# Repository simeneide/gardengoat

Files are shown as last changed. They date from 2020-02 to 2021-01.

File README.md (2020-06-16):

# gardengoat

## Installation of raspberry pi

### Install os + wifi
1. Download full raspberian at  https://www.raspberrypi.org/downloads/raspbian/
2. Flash sd card
3. Create file "ssh" in boot directory
4. Connect pi to network
5. Set configs in `sudo raspi-config`
    a. Set wifi ssid+pwd
    b. Set host name to gardengoat
6. Clone this repository: `git clone https://github.com/simeneide/gardengoat.git`
	
### Install gps module
1. Set the following in raspi-config:https://learn.adafruit.com/adafruit-ultimate-gps-hat-for-raspberry-pi/pi-setup

### Installing motor driver
Following [this](https://learn.adafruit.com/adafruit-dc-and-stepper-motor-hat-for-raspberry-pi/installing-software) instructions to install driver to motor:
1. Enable I2C: https://learn.adafruit.com/adafruits-raspberry-pi-lesson-4-gpio-setup/configuring-i2c
2. Install library: `sudo pip3 install adafruit-circuitpython-motorkit`

### Other packages
- apriltags (https://pypi.org/project/apriltags/) (need `apt-get update && apt-get install cmake`)
- Installed by building here: `https://github.com/AprilRobotics/apriltag`

pip3 install jupyterlab
apt-get install emacs

### TORCH and TORCHVISION
Installed from wheel on these:
https://github.com/nmilosev/pytorch-arm-builds

But for rpi4 there was some errors, so I installed a wheel after reading this comment:
https://github.com/nmilosev/pytorch-arm-builds/issues/4#issuecomment-527433112

Install from his wheel a bit longer down the thread, and rename those _C.**.so and _d.**.so files to _C.so and _d.so.

Torchvision works, but Pillow 7.0.0 was too new, so downgraded to 6.1 after some random comments I found.

Step-by-step:
- `sudo pip3 install torch-1.1.0-cp37-cp37m-linux_armv7l.whl`

Then if you try to run `sudo python3 -c "import torch"` you get:

```
Traceback (most recent call last):
  File "<string>", line 1, in <module>
  File "/usr/local/lib/python3.7/dist-packages/torch/__init__.py", line 79, in <module>
    from torch._C import *
ModuleNotFoundError: No module named 'torch._C'
```
Can be fixed by the following:
```
cd /usr/local/lib/python3.7/dist-packages/torch
sudo mv _C.cpython-37m-arm-linux-gnueabi.so _C.so
sudo mv _dl.cpython-37m-arm-linux-gnueabi.so _dl.so
```

### Local Bluetooth keyboard
Using the python keyboard package and requires root to run.
Advantage: You can drive the car locally without need for stable wifi.

Need to be connected and paired to the keyboard:
Sometimes needs to be repaired:
```
bluetoothctl
remove 2C:33:61:E0:77:84
pair 2C:33:61:E0:77:84
connect 2C:33:61:E0:77:84
```
### ps4 controller
Doesnt work yet..

`sudo pip install pyPS4Controller`

sudo pip3 install ds4drv

sudo wget https://raw.githubusercontent.com/chrippa/ds4drv/master/udev/50-ds4drv.rules -O /etc/udev/rules.d/50-ds4drv.rules
sudo udevadm control --reload-rules
sudo udevadm trigger

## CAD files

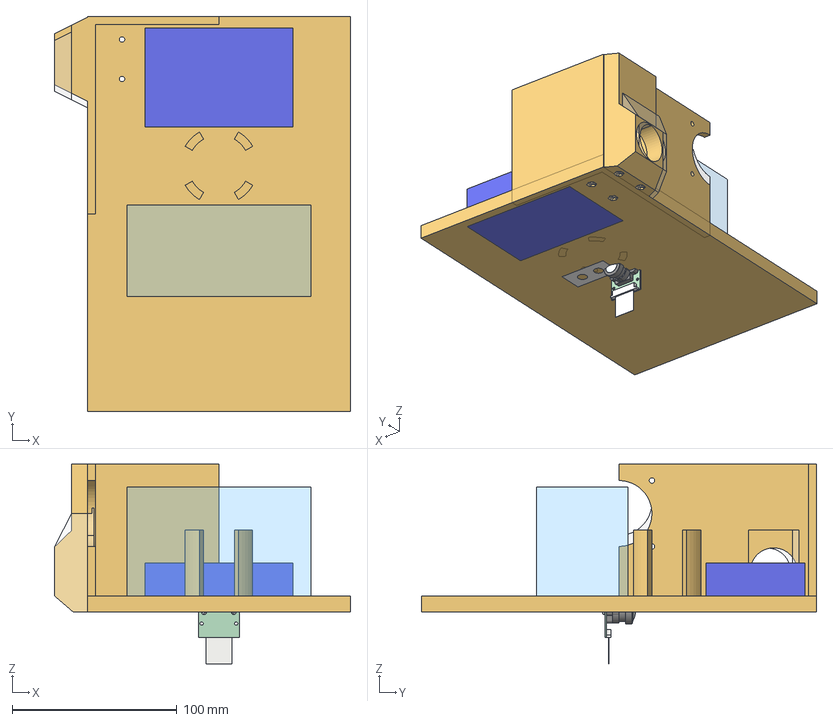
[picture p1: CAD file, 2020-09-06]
CAD/goat-ver3.FCStd
180.0 x 240.0 x 121.4 mm
Body-q11-lower
body-battery
body-full
body-rpi
Body-knife-blade
Raspberry Pi Camera (G) 160\X\B0
Raspberry Pi Camera (G) 160\X\B001
Raspberry Pi Camera (G) 160\X\B002
Raspberry Pi Camera (G) 160\X\B003
Raspberry Pi Camera (G) 160\X\B004
Raspberry Pi Camera (G) 160\X\B005
Raspberry Pi Camera (G) 160\X\B006
Raspberry Pi Camera (G) 160\X\B007

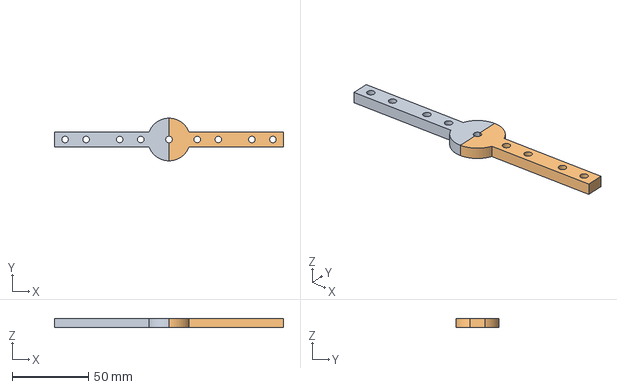
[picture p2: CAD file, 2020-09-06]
CAD/knifeblade.FCStd
150.0 x 28.0 x 6.00 mm
Body (Mirror #1)

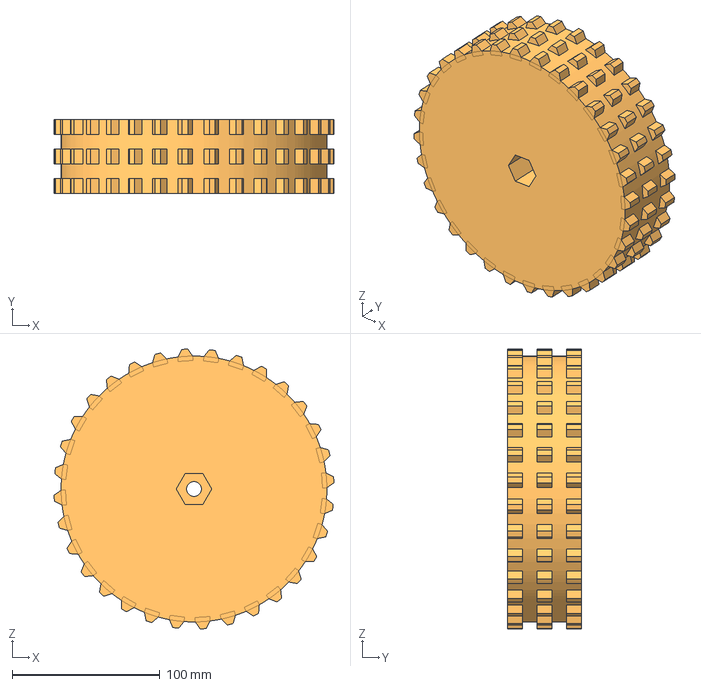
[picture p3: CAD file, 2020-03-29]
CAD/wheel-knast.FCStd
189.6 x 50.0 x 189.6 mm

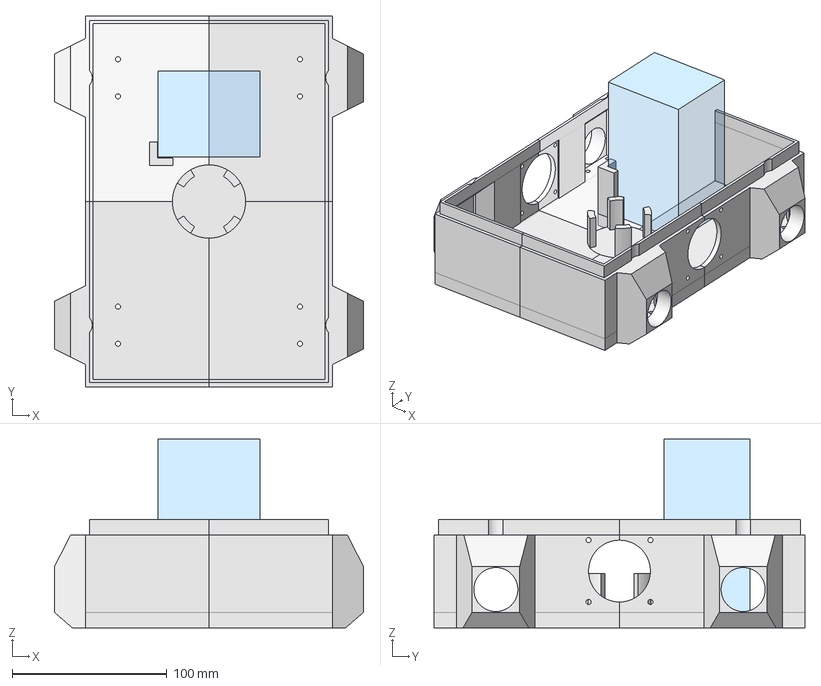
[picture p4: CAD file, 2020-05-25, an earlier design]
CAD/goat-ver2.FCStd
200.0 x 240.0 x 122.0 mm
Body-grasscutter
Body-q11-lower
Body-q11-lower (Mirror #1)
Body-q11-lower (Mirror #2)
Body-q11-lower (Mirror #3)
body-battery

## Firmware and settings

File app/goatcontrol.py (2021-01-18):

################
#### MOTOR ####
import cv2, queue, threading, time
import time
import numpy as np
import logging
import pyrealsense2 as rs
import sys
import time
import RPi.GPIO as GPIO
#import picamera
#import apriltag
# from gps3.agps3threaded import AGPS3mechanism
        
def output_list(pins, value):
    for pin in pins:
        GPIO.output(pin, value)

class Car:
    def __init__(self):
        self.gpio_map = {
            'left' : {
                'forward' : [6,26],
                'backward' : [13,20]
            },
            'right' : {
                'forward' : [5,19],
                'backward' : [12,16]
            }
        }
        GPIO.cleanup()
        GPIO.setmode(GPIO.BCM)
        for side, motors in self.gpio_map.items():
            for key, val in motors.items():
                print(f"{side}-{key}-{val}")
                GPIO.setup(val, GPIO.OUT)
        logging.info(f"driving controls initialized.")
        
    def drive(self, left=0, right=0, cut=False , *args, **kwargs):
        if left>=0:
            output_list(self.gpio_map['left']['forward'], left)
            output_list(self.gpio_map['left']['backward'], 0)
        if left<=0:
            output_list(self.gpio_map['left']['backward'], -left)
            output_list(self.gpio_map['left']['forward'], 0)
        if right>=0:
            output_list(self.gpio_map['right']['forward'], right)
            output_list(self.gpio_map['right']['backward'], 0)
        if right<=0:
            output_list(self.gpio_map['right']['backward'], -right)
            output_list(self.gpio_map['right']['forward'], 0)
            
    def close(self):
        GPIO.cleanup()
        
        
################
#### SENSORS ####
import asyncio
def rgb2gray(rgb):
    return np.dot(rgb[...,:3], [0.2989, 0.5870, 0.1140])

# GET GPS SIGNAL
class GPSTracker:
    def __init__(self):
        self.agps_thread = AGPS3mechanism()  # Instantiate AGPS3 Mechanisms
        self.agps_thread.stream_data()  # From localhost (), or other hosts, by example, (host='gps.ddns.net')
        self.agps_thread.run_thread()  # Throttle time to sleep after an empty lookup, default '()' 0.2 two tenths of a second

    def __call__(self):
        return {
            
            'lat' : self.agps_thread.data_stream.lat,
            'lon' : self.agps_thread.data_stream.lon,
            'speed' : self.agps_thread.data_stream.speed,
        }

class EmptySensor():
    def __init__(self, **kwargs):
        logging.info("inizalizing empty sensor")
    def step(self,*args, **kwargs):
        return {}
    def close(self, *args, **kwargs):
        pass

class GoatSensor:
    def __init__(self, apriltag=False):
        self.loop = asyncio.new_event_loop()
        self.sensors = {}
        self.sensors['realsense'] = DepthCamera()
        
        # APRILTAG INIT
        self.apriltag = apriltag
        if self.apriltag:
            self.detector_apriltag = apriltag.Detector()
        
        # GPS SENSOR
        #self.sensor['gps'] = GPSTracker()
        
        time.sleep(2)
        
    def __call__(self):
        result = self.loop.run_until_complete(self.fetch_async())
        return result

    async def fetch_async(self):
        state = {name:
            self.loop.run_in_executor(None, sensor)
            for name, sensor in self.sensors.items()}
        state = await gather_dict(state)
        
        result = {}
        for topkey, d in state.items():
            for key, val in d.items():
                result[key] = val
        return result

    def close(self):
        logging.info("closing sensors..")
        for key, val in self.sensors.items():
            try:
                val.close()
                logging.info(f"closed sensor: {key}.")
            except Exception as e:
                logging.info(f"FAILED to close sensor: {key}. Exception:")
                print(e)
                
    def detect_apriltag(self):
        gray = rgb2gray(self.img).astype(np.uint8)
        apriltags = self.detector_apriltag.detect(gray)
        if len(apriltags) == 0:
            aptag = None
        elif len(apriltags)>0:
            obj = apriltags[0]
            aptag = {'corners' : obj.corners.astype("int"),
                    'center' : obj.center,
                    'centerpct' : obj.center / self.resolution
                    }
        return aptag

async def gather_dict(tasks: dict):
    async def mark(key, coro):
        return key, await coro

    return {
        key: result
        for key, result in await asyncio.gather(
            *(mark(key, coro) for key, coro in tasks.items())
        )
    }

def coord2array(coord):
    return np.array([coord.x, coord.y, coord.z])

class DepthCamera:
    def __init__(self):
        self.pipe = rs.pipeline()
        self.fps=10
        self.resolution = {'x':640,'y':480}
        conf = rs.config()
        conf.enable_stream(rs.stream.accel)
        conf.enable_stream(rs.stream.gyro)
        #conf.enable_stream(rs.stream.depth)
        #conf.enable_stream(rs.stream.color)

        #Setup streaming and recording
        conf.enable_stream(rs.stream.depth, self.resolution['x'], 
                                    self.resolution['y'])
        conf.enable_stream(rs.stream.color, self.resolution['x'], 
                                    self.resolution['y'])
        self.profile = self.pipe.start(conf)
        self.depth_scale = self.profile.get_device().first_depth_sensor().get_depth_scale()
        for x in range(5):
          self.pipe.wait_for_frames()
        logging.info("depth camera initialized.")
        
    def __call__(self):
        frame = self.pipe.wait_for_frames()
        out = {}
        #out['frame'] = frame
        out['camera'] = np.asanyarray(frame.get_color_frame().get_data())
        out['depth_frame'] = np.asanyarray(frame.get_depth_frame().get_data())#*self.depth_scale
        out['pose'] = coord2array(frame[2].as_motion_frame().get_motion_data()) # unsure whether this is motion of accel
        out['acceleration'] = coord2array(frame[3].as_motion_frame().get_motion_data()) # unsure whether this is motion of accel
        return out
    def close(self):
        self.pipe.stop()

class GoatCamera:
    """ 
    Module that constantly reads the camera and gives you the latest frame when called.
    grabbed from here: https://stackoverflow.com/questions/43665208/how-to-get-the-latest-frame-from-capture-device-camera-in-opencv
    """
    def __init__(self, name=0, width =480, height=640):
        self.cap = cv2.VideoCapture(name)
        self.cap.set(cv2.CAP_PROP_FRAME_WIDTH, width)
        self.cap.set(cv2.CAP_PROP_FRAME_HEIGHT, height)
        
        self.run_thread=True
        self.q = queue.Queue()
        t = threading.Thread(target=self._reader)
        t.daemon = True
        t.start()

    # read frames as soon as they are available, keeping only most recent one
    def _reader(self):
        while self.run_thread:
          ret, frame = self.cap.read()
          if not ret:
            break
          if not self.q.empty():
            try:
              self.q.get_nowait()   # discard previous (unprocessed) frame
            except queue.Empty:
              pass
          self.q.put(frame)

    def __call__(self):
        return self.q.get()

    def close(self):
        self.run_thread = False
        self.cap.release()
        
if __name__ == "__main__":
    print("Testing motor capabilities")
    car = Car()
    car.drive(-1,1, cut=False)
    time.sleep(1)
    car.drive(0,0, cut=True)
    time.sleep(1)
    car.close()
    print("Motor test done.")

    print("Test sensors")
    sensor = GoatSensor()
    for i in range(5):
        print(sensor())
        time.sleep(1.0)
    print("sensor test done.")

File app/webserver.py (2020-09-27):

from aiohttp import web
import asyncio
import threading
import time
HTML = """
  <head>
    <title>Gardengoat</title>
    <style type="text/css">
      .navbutton{
        height:30%;
        width:33%;
        font-size:100px
      }
    .widebutton{
        height:10%;
        width:49%;
        font-size:100px
      }
    </style>
  </head>
<button class="navbutton" onclick="sendkey('forwardleft')">↖</button>
<button class="navbutton" onclick="sendkey('forward')">↑</button>
<button class="navbutton" onclick="sendkey('forwardright')">↗</button>
<button class="navbutton" onclick="sendkey('left')">←</button>
<button class="navbutton" onclick="sendkey('stop')">STOP</button>
<button class="navbutton" onclick="sendkey('right')">→</button>
<button class="navbutton" onclick="sendkey('backandturn')">↪️</button>
<button class="navbutton" onclick="sendkey('backward')">↓</button>
<button class="navbutton" onclick="sendkey('AI')">💾</button>

<button class="widebutton" onclick="sendkey('cut')">cut</button>
<button class="widebutton" onclick="sendkey('speed')">speed</button>

<script>
  function sendkey(key) {
      fetch("/".concat(key))
  }
</script>
"""

class Webagent:
    def __init__(self):
        self.key = "stop"
        self.cut = 0
        self.speed = 1
        t = threading.Thread(target=self.run_server, args=(self.aiohttp_server(),))
        t.start()
        return None

    async def index(self, request: web.Request) -> web.Response:
        return web.Response(text=HTML, content_type="text/html")

    async def key_request(self, request: web.Request) -> web.Response:
        key = request.match_info.get('key')#.encode()
        self.key = key
        print(self.key)
        if key == "cut":
            self.cut= (1-self.cut)
        return await self.index(request)

    def setup_routes(self, app):
        app.router.add_get('/', self.index)
        app.router.add_get('/{key}', self.key_request)

    def aiohttp_server(self):
        app = web.Application()
        self.setup_routes(app)
        runner = web.AppRunner(app)
        #web.run_app(app, port=9999)
        return runner

    def run_server(self,runner):
        loop = asyncio.new_event_loop()
        asyncio.set_event_loop(loop)
        loop.run_until_complete(runner.setup())
        site = web.TCPSite(runner, port= 80)
        loop.run_until_complete(site.start())
        loop.run_forever()

    def __call__(self, *args, **kwargs):
        
        if self.key == "stop":
            self.cut = 0
            action = {'left' : 0, 'right' : 0, "cut" : 0}
        elif self.key == "forward":
            action = {'left' : 1, 'right' : 1}
        elif self.key == "backward":
            action = {'left' : -1, 'right' : -1}
        elif self.key == "left":
            action = {'left' : -1, 'right' : 1}

        elif self.key == "right":
            action = {'left' : 1, 'right' : -1}

        elif self.key == "forwardleft":
            action = {'left' : 0.5, 'right' : 1}

        elif self.key == "forwardright":
            action = {'left' : 1, 'right' : 0.5}

        else:
            action = {}

        # Special values:
        action['action'] = self.key
        action['cut'] = self.cut
        return action

if __name__ == "__main__":
    import time
    server = Webagent()
    while True:
        print(server.key, server())
        time.sleep(5)

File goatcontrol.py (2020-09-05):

################
#### MOTOR ####

from adafruit_motorkit import MotorKit
import time

class Car:
    """
    Car can do three different things:
    - Throttle = discrete {-1,0,1}: -1 is backward, 0 is standing and +1 is forward
    - Steer = continuous [-1,1] where -1 is going left and +1 is going right
    - cut: False/True
    """
    def __init__(self):
        self.kit = MotorKit()
        self.cutter = self.kit.motor4
        self.motor_left = [self.kit.motor1]
        self.motor_right = [self.kit.motor2]
        self.all_motors = self.motor_left + self.motor_right + [self.cutter]
        
    def stop(self, tid = 0):
        """
        The most important function. stops all motors!
        """
        time.sleep(tid)
        for m in self.all_motors:
            m.throttle = 0
            
    def _cut(self, action):
        if action == True:
            self.cutter.throttle = 1.0
        else:
            self.cutter.throttle = 0
                    
    def _motion(self, left=0, right=0):
        """
        Controls how much output on each set of motors.
        """        
        for m in self.motor_left:
            m.throttle = -left
        for m in self.motor_right:
            m.throttle = -right

    def drive(self, left = 0, right = 0, cut = False, *args, **kwargs):
        self._motion(left = left, right = right)
        self._cut(cut)

################
#### SENSORS ####

import time
import picamera
import numpy as np
import apriltag

def rgb2gray(rgb):
    return np.dot(rgb[...,:3], [0.2989, 0.5870, 0.1140])

# GET GPS SIGNAL
from gps3.agps3threaded import AGPS3mechanism
class GPSTracker:
    def __init__(self):
        self.agps_thread = AGPS3mechanism()  # Instantiate AGPS3 Mechanisms
        self.agps_thread.stream_data()  # From localhost (), or other hosts, by example, (host='gps.ddns.net')
        self.agps_thread.run_thread()  # Throttle time to sleep after an empty lookup, default '()' 0.2 two tenths of a second

    def __call__(self):
        return {
            
            'lat' : self.agps_thread.data_stream.lat,
            'lon' : self.agps_thread.data_stream.lon,
            'speed' : self.agps_thread.data_stream.speed,
        }

class GoatSensor:
    def __init__(self, apriltag=False):
        self.camera = picamera.PiCamera()
        self.resolution = (256,256)
        self.camera.resolution = self.resolution
        #self.camera.framerate = 24
        self.camera.crop = (0.0, 0.0, 1.0, 1.0)
        # Init buffer
        self.rgb = bytearray(self.camera.resolution[0] * self.camera.resolution[1] * 3)
        self.img = np.empty( self.resolution+ (3,), dtype=np.uint8)
        
        # APRILTAG INIT
        self.apriltag = apriltag
        if self.apriltag:
            self.detector_apriltag = apriltag.Detector()
        
        # GPS SENSOR
        self.gps = GPSTracker()
        
        time.sleep(2)
    def close(self):
        self.camera.close()
    def capture(self):
        self.camera.capture(self.img,use_video_port=True, format= 'rgb')
        return self.img

    def detect_apriltag(self):
        gray = rgb2gray(self.img).astype(np.uint8)
        apriltags = self.detector_apriltag.detect(gray)
        if len(apriltags) == 0:
            aptag = None
        elif len(apriltags)>0:
            obj = apriltags[0]
            aptag = {'corners' : obj.corners.astype("int"),
                    'center' : obj.center,
                    'centerpct' : obj.center / self.resolution
                    }
        return aptag
    
    def step(self, show_apriltag = True):
        state = {}
        state['image'] = self.capture()
        
        
        coord = self.gps()
        state.update(coord)
        if self.apriltag:
            state['apriltag'] = self.detect_apriltag()
            if show_apriltag & (state['apriltag'] is not None):
                corners = aptag['corners']
                state['image'][corners[0,1]:corners[2,1], corners[0,0]:corners[2,0],1] = 200
            
        return state

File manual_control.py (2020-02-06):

import pygame
import io

# Init car
import goatcontrol
from pygame.locals import *
import utils
import numpy as np
car = goatcontrol.Car()
recorder = utils.SaveTransitions()
discrete_timer = utils.Discretize_loop(0.2)

# Init camera
camera = goatcontrol.GoatCam()
# Init pygame 
pygame.init()
screen = pygame.display.set_mode(camera.resolution)
pygame.display.set_caption('GardenGoat')
x = (screen.get_width() - camera.resolution[0]) / 2
y = (screen.get_height() - camera.resolution[1]) / 2


# DEFAULT PARS (ie dont drive, steer or cut)
def keyboard_control(*args, **kwargs):
    keys = pygame.key.get_pressed()
    action = {
        'throttle' : 0,
        'steer' : 0,
        'cut' : 0
    }

    if keys[K_w]:
        action['throttle'] = 1
    elif keys[K_s]:
        action['throttle'] = -1
    elif keys[K_a]:
        action['steer'] = -1
    elif keys[K_d]:
        action['steer'] = 1

    if keys[K_SPACE]:
        action['cut'] = True

    return action

import time
def drive_to_tag(state):
    action = {
        'throttle' : 0,
        'steer' : 0,
        'cut' : 0
    }
    apriltag = state['apriltag']
    if apriltag:
        angle = (apriltag['centerpct'][0]-0.5).round(3)
        if abs(angle) <0.03:
            action['throttle'] = 1
            action['steer'] = 0
        else:
            action['throttle']=0
            action['steer'] = np.sign(angle)
            
        print(f"throttle = {action['throttle']}, steer = {action['steer']}, angle: {angle}")
    else:
        action['throttle'] = 0.0
        action['steer'] = 1
        print(f"throttle = {action['throttle']}, steer = {action['steer']}, searching..")
    return action

# Main loop
exitFlag = True

## LOAD MODEL
import torch
import model_drive
model = torch.load("model.pickle")

def action_model(state):
    img = state.get("image")
    action = {
        'throttle' : 0,
        'steer' : 0,
        'cut' : 0
    }
    
    if img is None:
        return action
    yhat = model(model_drive.tr(img).unsqueeze(0))
    action_cat = int(yhat.argmax())

    if action_cat==0:
        action['throttle'] = 1
    elif action_cat==1:
        action['throttle'] = -1
    elif action_cat==2:
        action['steer'] = -1
    elif action_cat==3:
        action['steer'] = 1
    return action

state = {} # Init state
while(exitFlag):
    discrete_timer.start()
    
    for event in pygame.event.get():
        if(event.type is pygame.MOUSEBUTTONDOWN or 
            event.type is pygame.QUIT):
            exitFlag = False
    screen.fill(0)

    action = action_model(state)
    car.drive(actiondict=action)
    
    ## CONTROL SEQUENCE
    state = camera.step()
    img = state['image']
    
    
    #time.sleep(0.3)
    #car.stop()
    #time.sleep(0.05)
    
    import random
    if random.random() > 0.5:
        img_pygame = pygame.surfarray.make_surface(np.swapaxes(img,0,1))
        if img_pygame:
            screen.blit(img_pygame, (x,y))
            pygame.display.update()
        
    ### RECORD EVENTS ###
    if sum([abs(val) for key, val in action.items()]) > 0: # i.e any action was taken
        recorder.save_step(
            action = action, 
            newimage = img)
        
    discrete_timer.end()
    print("h")

camera.close()
pygame.display.quit()
car.stop()

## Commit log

2020-01-18 remap right motor
2020-01-19 make camera module and integrate apriltag
2020-02-05 fix next and prev img
    [utils.py]
2020-02-29 first iteration of wheel
    [wheel-knast.FCStd]
2020-03-29 save all sensors, not just image
2020-04-28 ver1 of lower body fully printed
    [goat-ver2.FCStd]
2020-05-15 fix wifi keyboard driving
    [agents.py, drive.py]
2020-05-25 fix wheel further apart + battery
    [goat-ver2.FCStd]
2020-07-01 steer instead of reverse, lower th
    [models.py]
2020-09-06 cad files
    [goat-ver3.FCStd, knifeblade.FCStd]
2020-09-06 installations and trying. motors work but not camera
2020-09-07 add empty sensor
2020-09-12 running with camera and jupyter env
2020-09-24 update to new sensor (realsense) and drive control (l298)
2020-09-25 make a model runnable on device
2021-01-18 add average depth driver
